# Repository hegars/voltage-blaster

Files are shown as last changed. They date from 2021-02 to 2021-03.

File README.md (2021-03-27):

# Voltage Blaster Mod

Voltage Blaster is a very simple circuit, which provides -5V through ISA slot
for systems with power supply which don't provide such voltage. It was originaly created
in cooperation between PhilsComputerLab and Necroware then forked and modified by Hegars.

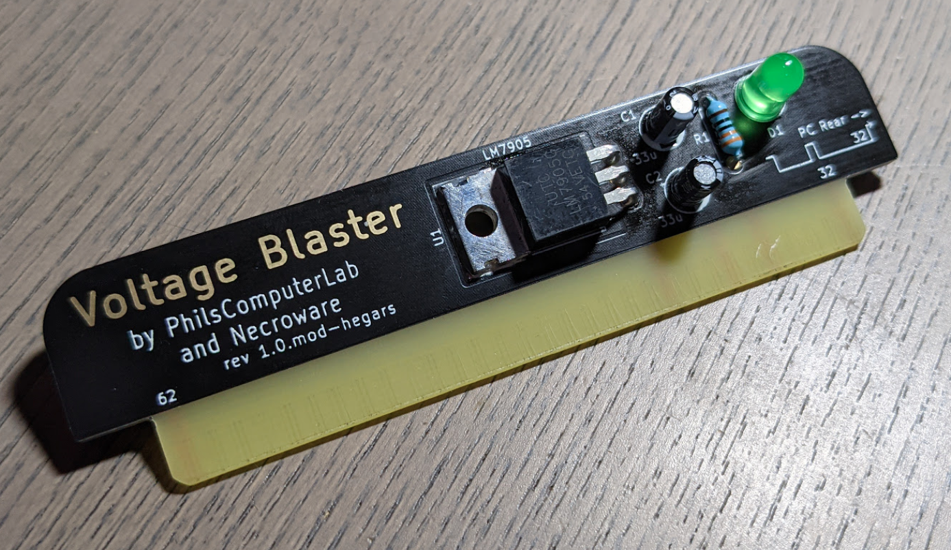
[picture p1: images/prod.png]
voltage-blaster-pcb


## Changes From Necroware version

PCB
* Updated - Pulled Mask from ISA Cconnector
* Updated - Pulled Mask from the top of TO-220 package to allow soldering
* Added - Linked copper zone beneath TO-220 package to -12v for soldering 
* Updated - NPTH mount on TO-220 package changed to PTH
* Added - Added Vias under TO-220 for heat transfer to rear copper zone
* Added - Added Copper zone on rear for heat sinking and capacitance (Linked at -12v)
* Updated - Slight components aliginments
* Moved - Logo changed from Silk to Mask and moved credits around
* Updated - Version number
* Updated - PCB corners rounded
* Updated - "PC Rear" locator to make it a bit more clear the direction
* Added - Pin numbers added for relevent pins for refernece
* Removed - Unused Pins on ISA Connector 

SCH
* Updated - Changed to global lables
* Updated - Version number

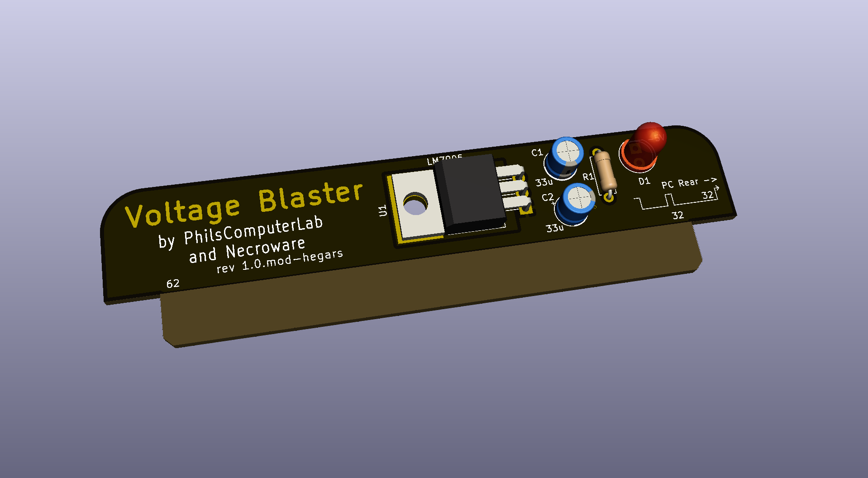
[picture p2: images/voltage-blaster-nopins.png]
voltage-blaster-pcb-nopin

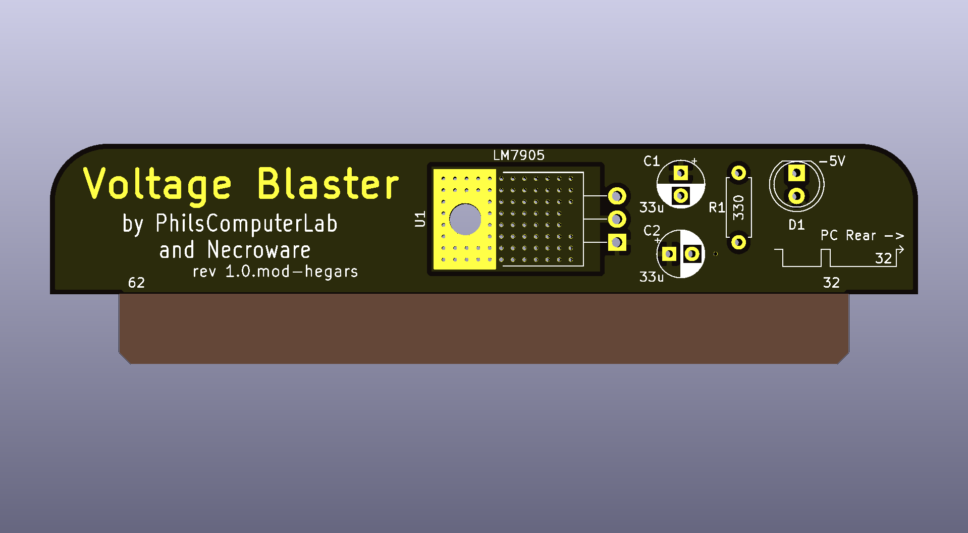
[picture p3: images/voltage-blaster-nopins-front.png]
voltage-blaster-pcb-nopin

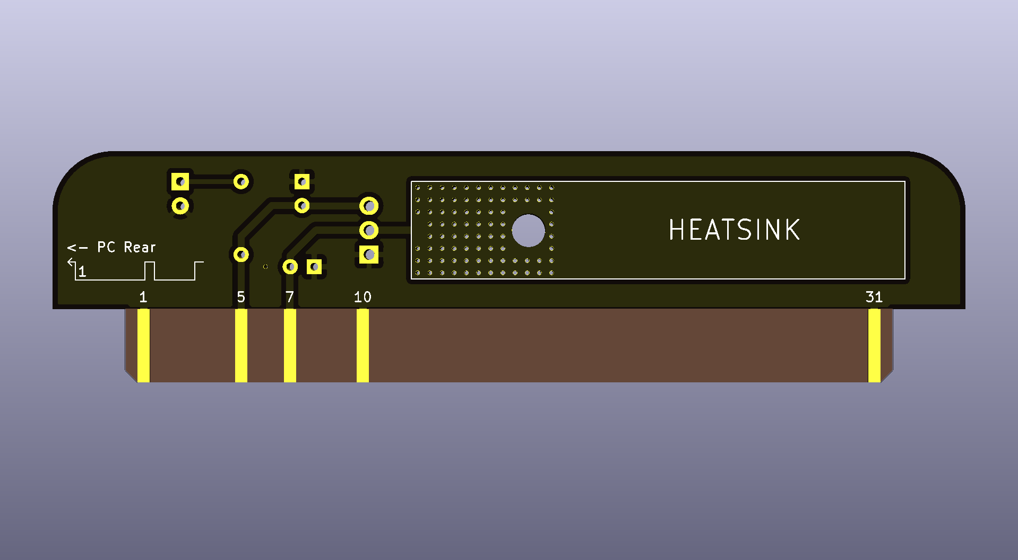
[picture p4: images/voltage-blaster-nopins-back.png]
voltage-blaster-pcb-nopin


Many thanks to Necroware and PhilsComputerLab, I owe you some beers..

# Voltage Blaster SMD

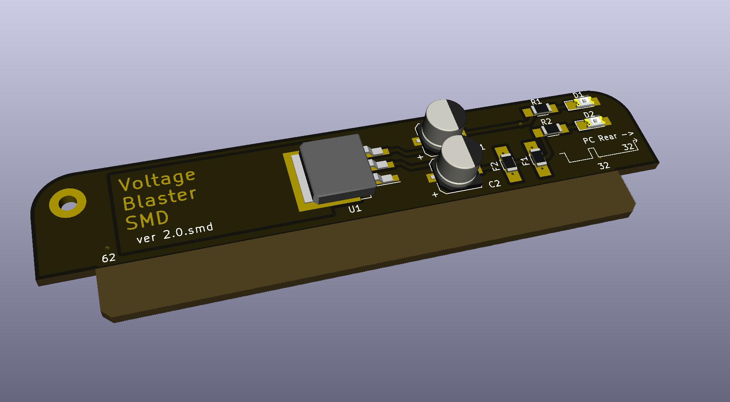
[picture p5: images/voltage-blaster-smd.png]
voltage-blaster-pcb-smd


In Version 2 I have moved all components to SMD variants

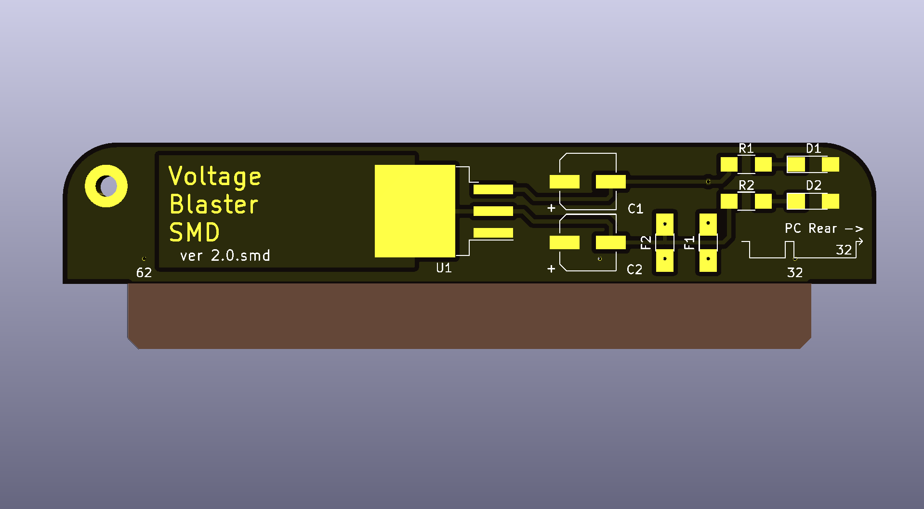
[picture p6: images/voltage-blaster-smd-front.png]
voltage-blaster-pcb-smd

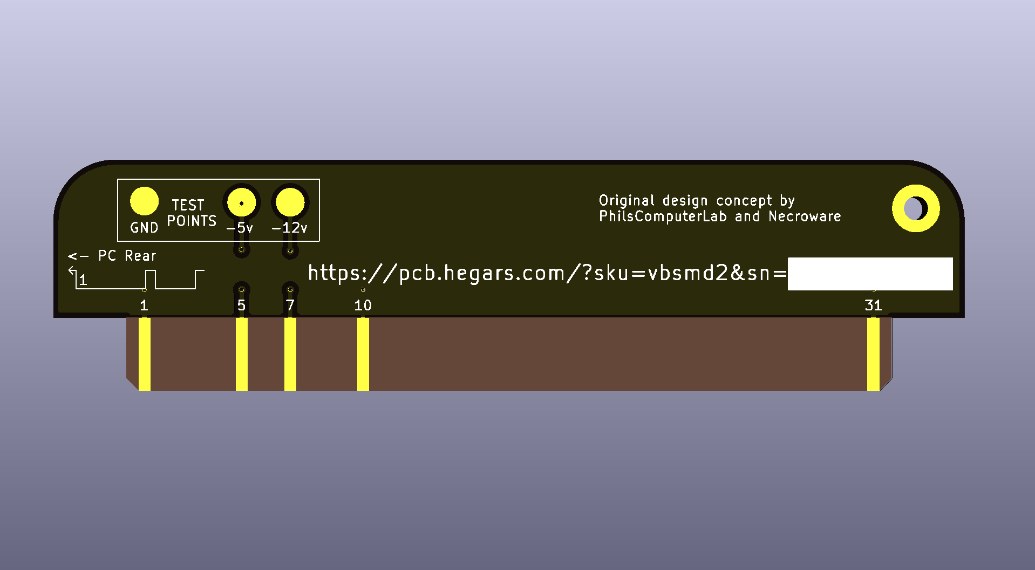
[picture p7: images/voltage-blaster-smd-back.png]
voltage-blaster-pcb-smd


## SMD Changelog 

* Added - SMD version with TO-263-3 package (LM2990S-5.0/NOPB LCSC-C201697)
* Updated - Componets to SMD variants
* Added - PTC Fuses on both power rails
* Added - Mounting hole for reasons
* Added - Test Points on rear for science
* Added - LED for -12v rail
* Moved - Logo and credits to rear
* Updated - Verison numbers
* Add? - Minimum load resistor?

## SMD BOM

Reference  |#  |LCSC   |Description
-----------|---|-------|-------------------------------------
U1         | 1 |C201697| linear voltage regulator
C1,C2      | 2 |C88824 | electrolytic capacitor 33µF
F1         | 1 |C692148| fuse
F2         | 1 |C692149| fuse
D1         | 1 |C192678| light emitting diode
D2         | 1 |C192674| light emitting diode
R1,R2      | 1 |C269588| resistor

# Original Voltage Blaster Description

## Why do I need this?

Back in the days of XT and AT compatible computers the standard power supply had
to provide 5V, 12V, -12V and -5V. A lot of hardware, especially sound cards,
needed -5V to work properly. This voltage was provided for the ISA expansion
cards on the pin B5. As time passed, AT systems and compatible power supplies
were replaced by ATX. In the beginning they also provided -5V, but then less and
less expansion cards needed such voltage and as soon as ISA was considered 
obsolete, ATX standard eventually dropped -5V rail requirement. Today it is not
possible to buy a new AT power supply, but ATX power supplies can be used
through an adapter. However, since almost none of the modern ATX power supplies
will provide -5V, you could run into problems, when trying to use an old ISA
expansion card, which needs this voltage. Famous examples are Creative Sound
Blaster 2.0, Pro Audio Spectrum sound cards and many others. This is where the
Voltage Blaster comes into play.

## How does it work?

All voltage pins in the ISA slots are directly connected to each other and to
the PSU. When using a PSU without -5V support, the ISA slot pin B5 is just
floating. The idea behind the Voltage Blaster is very simple. What if one of the
ISA expansion cards will provide -5V and feed it through the ISA slot in
reverse. Well since the ISA slot pin B7 provides -12V, it's just a matter of
using a linear voltage regulator LM7905 and connect its output to the pin B5 of
the ISA slot.

## Bill of materials

Reference  |#  |LCSC   |Description
-----------|---|-------|-------------------------------------
U1         | 1 |C427634| linear voltage regulator LM7905
C1,C2      | 2 |C3314  | electrolytic capacitor 33µF
D1         | 1 |C99697 | light emitting diode (optional)
R1         | 1 |C58608 | resistor 330 Ohm (optional)

Parts D1 and R1 are optional and are only required if you want that the diode is
lighting, when -5V are generated.

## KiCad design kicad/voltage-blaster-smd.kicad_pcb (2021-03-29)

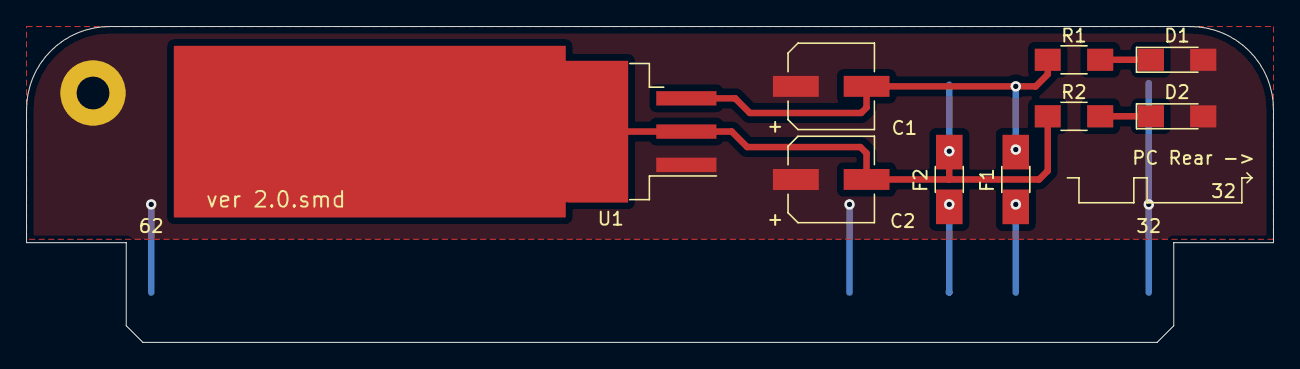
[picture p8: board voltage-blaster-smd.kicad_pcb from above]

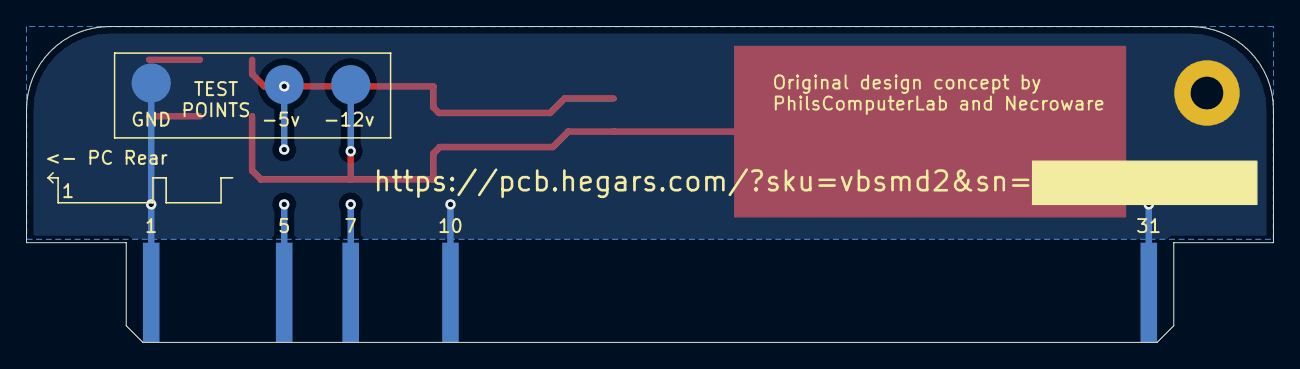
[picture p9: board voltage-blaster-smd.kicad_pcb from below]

Board: 2 copper layers, 95.2 x 24.1 mm, 14 parts (3 on the bottom side), 5 nets.

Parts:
C1, C2: 33u; CP_Elec_6.3x5.7
D1: -5V; LED_1206_HandSoldering
D2: -12V; LED_1206_HandSoldering
F1, F2: Fuse; Fuse_SMD1206_HandSoldering
H1: MountingHole_Pad; MountingHole_2.5mm_Pad
J1: Bus_ISA_8bit; ISA_8BIT_EDGE_voltageblaster
R1, R2: 330; R_1206_HandSoldering
TP1, TP2, TP3: TestPoint; Measurement_Point_Round-SMD-Pad_Big
U1: LM7905; TO-263-3_TabPin2

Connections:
-5V: C1.2, F1.2, J1.5, R1.1, TP1.1, U1.3
-12V: C2.2, F2.2, J1.7, R2.1, TP2.1, U1.2
GND: C1.1, C2.1, D1.2, D2.2, H1.1, J1.1, J1.10, J1.31, TP3.1, U1.1
unnamed: D1.1, R1.2
unnamed: D2.1, R2.2

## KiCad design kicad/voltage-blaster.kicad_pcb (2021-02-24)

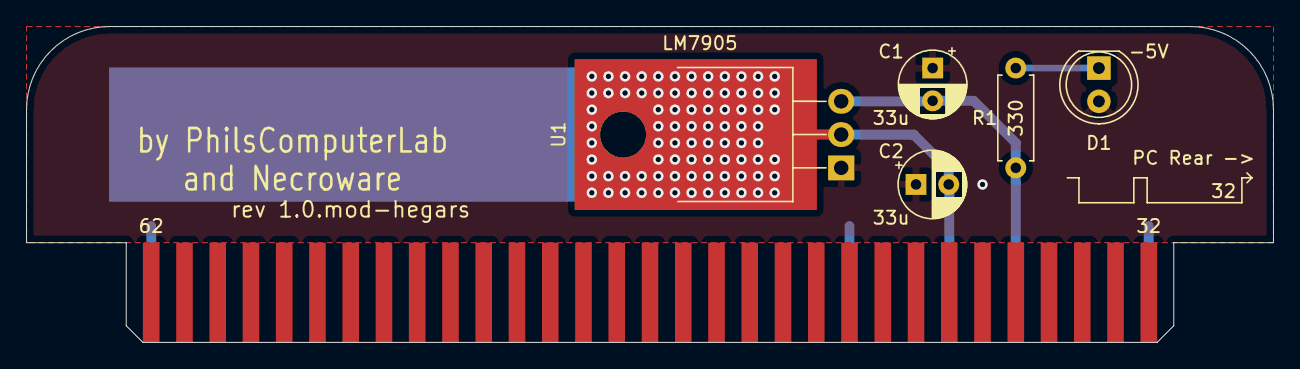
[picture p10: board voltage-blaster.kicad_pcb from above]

Board: 2 copper layers, 95.2 x 24.1 mm, 6 parts (0 on the bottom side), 4 nets.

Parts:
C1, C2: 33u; CP_Radial_D5.0mm_P2.50mm
D1: -5V; LED_D5.0mm
J1: Bus_ISA_8bit; ISA_8BIT_EDGE
R1: 330; R_Axial_DIN0207_L6.3mm_D2.5mm_P7.62mm_Horizontal
U1: LM7905; TO-220-3_Horizontal_TabDown

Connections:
-5V: C1.2, J1.5, R1.1, U1.3
-12V: C2.2, J1.7, U1.2
GND: C1.1, C2.1, D1.2, J1.1, J1.10, J1.31, U1.1
unnamed: D1.1, R1.2

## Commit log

2021-02-24 updated for nopins
    [voltage-blaster-nopins.kicad_pcb]
2021-03-22 added prod board images
2021-03-27 Added SMD variant
    [voltage-blaster-smd.kicad_pcb, voltage-blaster-smd.sch]
